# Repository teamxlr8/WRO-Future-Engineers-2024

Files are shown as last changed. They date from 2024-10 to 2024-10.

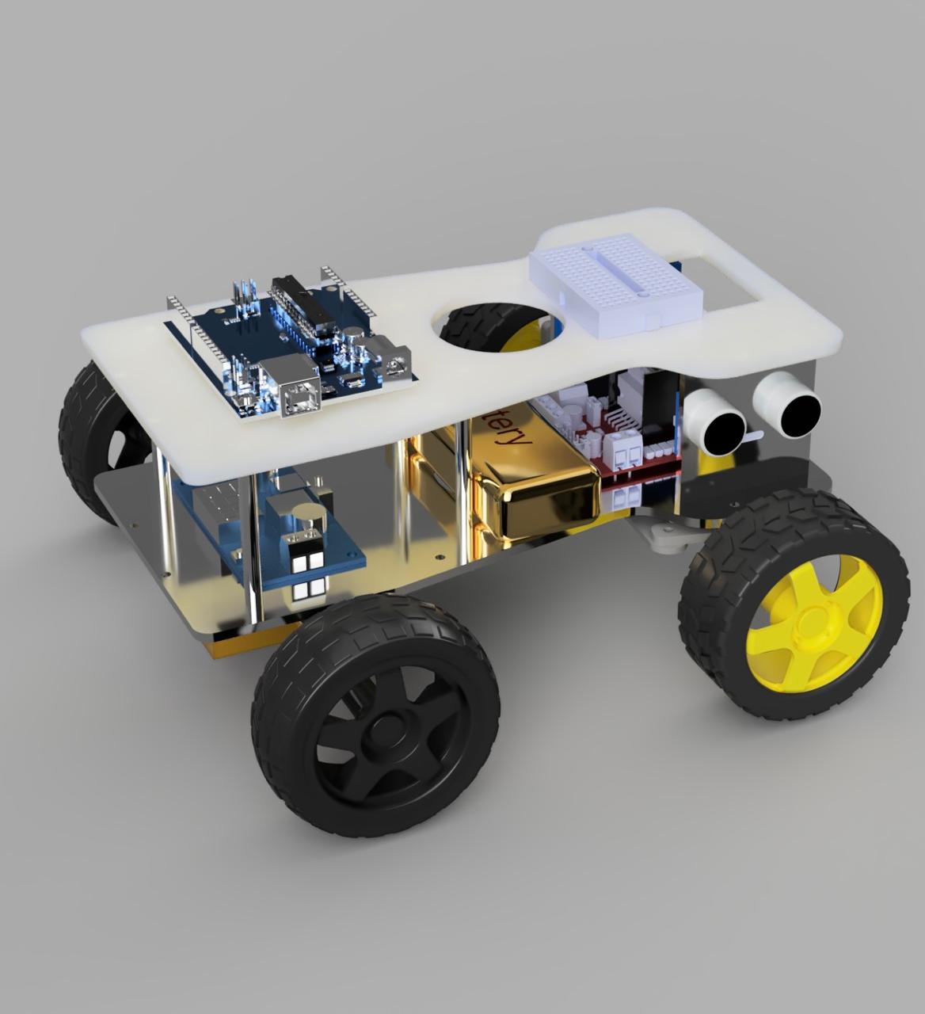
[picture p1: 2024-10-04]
models/6.jpeg

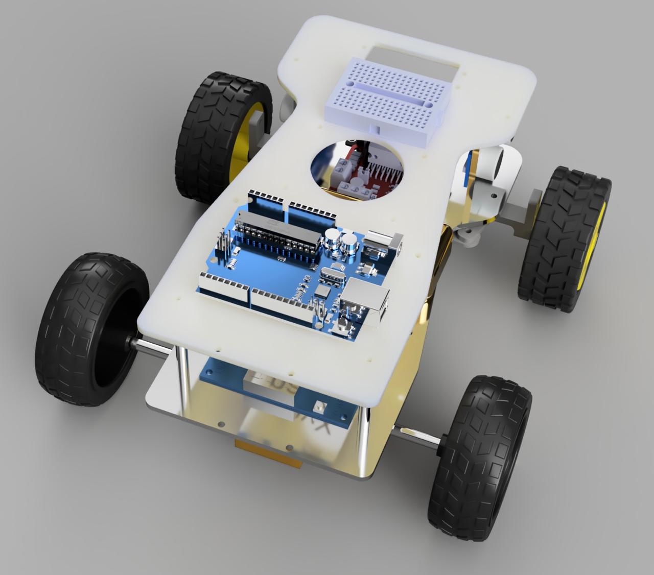
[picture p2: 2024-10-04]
models/4.jpeg

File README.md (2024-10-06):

# WRO Future Engineers 2024
## Introduction
Hello! This is team xlr8's WRO Future Engineer's repository. This repository includes details about our robot's construction, electricals, and software. We've recorded the progress of our robot and the various iterations we worked on throughout the process of preparing for the WRO competition.

As Team xlr8, our team's goal is to design and develop an advanced autonomous robot with precise steering capabilities to navigate a complex track effectively. Using engineering workflows and iterative testing, our intent is to optimize performance and showcase our innovation and problem-solving skills.

## Contents of This Repository
1. `t-photos`: Team Photos
2. `v-photos`: Robot's Photos
3. `video`: Video Demonstration of Our Running Robot
4. `schemes`: Schematic Diagrams
5. `src`: Software and Codes Required to Run Our Robot
6. `model`: Files for Model 
9. `other`: Detailed Descriptions of Components and Mechanisms

## Introduction
_This part must be filled by participants with the technical clarifications about the code: which modules the code consists of, how they are related to the electromechanical components of the vehicle, and what is the process to build/compile/upload the code to the vehicle’s controllers._

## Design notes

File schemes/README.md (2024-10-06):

This commit in our repository holds all the schematic diagrams that help understand the electricals connections in our robot.

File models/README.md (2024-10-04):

This folder holds the .step file for the final assembly of our robot, as well as photos of what it should look like. The .step file will help the viewer look into each part of the robot chassis and electricals, and it can make it easier to follow the tutorial using the timeline feature on Fusion 360. 

Since the .step file is too large to upload, we're adding a google drive link with the file uploaded on that: https://drive.google.com/drive/folders/1iC6DVvbiXgJcQIvjXP-3EXG4zTWpt-ap?usp=sharing

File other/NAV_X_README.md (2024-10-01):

We are using the NavX magnetometer in our robot in order to be able to measure and control the number of times the car circles around the inner boundary. Traditionally, the NavX magnetometer is a sensor commonly used in robotics and navigation applications to measure magnetic fields and determine orientation relative to the Earth's magnetic field. The core component of the NavX magnetometer is a 3-axis magnetometer, which measures the magnetic field strength along three perpendicular axes (X, Y, and Z). These measurements are often also refered to as roll, pitch and yaw respectively. We have explained these parameters in more detail below.

Moreover, the NavX sensor typically includes a microcontroller that processes the raw data from the magnetometer. The NavX magnetometer typically provides various interfaces for integration with robotics platforms, such as I2C, SPI, or UART. This makes it compatible with many microcontrollers and development boards. We have integrated the NavX with the Arduino Uno Board for this project.

Additionally, when combined with other sensors like accelerometers and gyroscopes, the NavX magnetometer can provide more accurate orientation and heading information through sensor fusion algorithms. These algorithms combine data from multiple sensors to reduce errors and noise. Also, to ensure accurate readings, the NavX magnetometer often requires calibration. This process involves moving the sensor through various orientations to map out and correct any magnetic distortions caused by nearby objects. For instance, the NavX magnetometer is used to help robots determine their heading and maintain a stable direction of travel. In automotive applications, the magnetometer can be used for electronic compasses and navigation systems. In our robot, we are using the NavX magnetometer to measure and account for turns taken. So, in each circle, the magnetometer should measure four turns, and should take three such circles with twelve total turns. We are integrating the NavX sensor with the Arduino board to be able to stop the robot when it does this.

Now, explaining the roll, pitch and yaw parameters… Yaw, pitch, and roll are three rotational degrees of freedom that describe the orientation of an object in 3D space. In the context of the NavX sensor, these terms refer to the angular orientation of a device, typically a robot or UAV, relative to its own coordinate system.

Roll is the rotation around the longitudinal axis (X-axis). It represents the tilt of the object from side to side. The NavX sensor measures roll using the accelerometer and gyroscope. The accelerometer detects the force of gravity to determine side-to-side tilt, while the gyroscope measures rotational changes around the longitudinal axis. Roll is essential for balance and stability. In a robot, the roll angle helps maintain equilibrium on uneven surfaces, while in a drone, it helps control the side-to-side tilt.

Pitch is the rotation around the lateral axis (Y-axis). It represents the tilt of the object forward or backward. The NavX sensor measures pitch using the accelerometer and gyroscope. The accelerometer detects the force of gravity, which indicates the tilt angle, while the gyroscope measures rotational changes around the lateral axis. Pitch is important for maintaining stability and orientation. For instance, in a drone, the pitch angle helps control the forward or backward tilt during flight.

Lastly, yaw is the rotation around the vertical axis (Z-axis). It represents the direction the object is facing horizontally, often referred to as the heading. In the NavX sensor, yaw is measured using the magnetometer and gyroscope. The magnetometer detects the direction of the Earth's magnetic field to determine heading, while the gyroscope measures rotational changes around the vertical axis. Yaw is crucial for navigation. For example, in a robot, the yaw angle helps determine the direction the robot is moving or facing.

The NavX sensor combines data from the accelerometer, gyroscope, and magnetometer to provide accurate measurements of yaw, pitch, and roll. This process, known as sensor fusion, involves filtering, calibration and fusion algorithms. Filtering is when raw data from each sensor is filtered to remove noise and improve accuracy. Then, sensors are calibrated to compensate for any biases or distortions. And lastly, advanced algorithms combine the data from all sensors to provide a stable and accurate estimate of the device's orientation.

While roll, pitch and yaw are all three equally important in understanding and manipulating the orientation of a robot, we will be focusing on the yaw value, since we just need to alter the robot’s ability to turn left or right, by adjusting its heading.

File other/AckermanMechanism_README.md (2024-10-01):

As mentioned in an earlier repository, we are using the Ackerman mechanism, which is linked to the servo motor, for the steering of the front two wheels. This mechanism, also known as Ackerman steering geometry, is a geometric arrangement of linkages in the steering of a vehicle. It is usually designed to solve the problem of wheels needing to trace out circles of different radii when steering. This mechanism is essential for ensuring that the wheels of a vehicle follow the correct path while turning, minimizing tire wear and improving handling. In our case, we are using this mechanism in order to improve the steering of our vehicle to the optimum level. This mechanism helped us because when we tried to directly connect the servo motor to the front two wheels, we saw that our robot was taking sharp turns and wasn’t able to control the same efficiently. However, this changed significantly when we tried the Ackerman steering. The mechanism provides more precise and predictable steering, enhancing vehicle control. Additionally, while testing, we also realised that by ensuring the wheels follow the correct path during a turn, the Ackerman mechanism reduces tire scrubbing and wear, hence improving the tire health.

How this mechanism traditionally works: When a vehicle turns, the inner and outer wheels must trace circles of different radii. The inner wheel needs to turn more sharply than the outer wheel. Ackerman steering geometry ensures that the inside front wheel turns at a sharper angle than the outside front wheel. It consists of three components, the steering arms (attached to the front wheels), the tie rods (connect the steering arms to the steering gear, which in our case is the servo motor) and the kingpin (the pivot point around which the wheel assembly turns, which in our case is an extension of the servo motor). Additionally, the correct Ackerman geometry involves positioning the steering arms such that, when extended, the lines drawn through the steering arms meet at the center of the rear axle. This ensures that all wheels are aligned with the turning circle's center. When the steering wheel is turned, the steering gear moves the tie rods, which in turn move the steering arms. Due to the specific angles and lengths of these components, the inner wheel turns more sharply than the outer wheel, maintaining the correct turning radii.

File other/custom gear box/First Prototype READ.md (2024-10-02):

This repository is for the custom gear box that we made for our robot. Initially, we were using the Rev Core Hex robot in our first prototype. The Rev Core Hex motor ran at a 125 rpm and weighed 200 grams. However, eventually we realised that this motor was functioning at a really slow speed. Even though this motor had a good torque but it was heavy, it had a very low rmp. Therefore, we weren't able to perform the task in an efficient manner with this motor. So, we tried to change the motor by using N20 motor which ran at 200 rpm and weighed 10 grams. This motor was light and had a high speed, but didn't have enough torque, so it wasn't a viable option either. Therefore, we finally decided to use the Bag motor which weighed 325 grams. For that, we needed to make a custom gear box, which has a 4:15 reduction (16:60). The pinion on the moitor runs at a 13,180 rpm which is powered by a Bag motor. This Bag motor is a VEX motor is a 13,180 rpm motor with 0.4 N-m stall torque. The 60 tooth gear connected to the output shaft by reduction gives a motor speed to 3,514 rpm. The reason that we have chosen to make the custom gear box is because we want to use a better motor. Here's the link to access the CAD for the custom gearbox https://grabcad.com/library/custom-gearbox-3 https://drive.google.com/file/d/15HoRaLY3t5rEGp8NuojFlwkP93zTSltt/view?usp=sharing

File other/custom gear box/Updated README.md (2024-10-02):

In our last iteration of the gear box, we were using readily available pinion gears and had attached those two together based on the CAD file we had created. However, when we actually made those changes on a box channel and then cut it and tested it, we realised that the two pinions were not compatible with each other. Due to this, there a slipping issue we weren't able to solve. The only way around this that we saw was creating our own custom pinion gear and then changing the gear box accordingly. So we did exactly that. Based on the new pinion, we altered the CAD file, after which we made a bigger and clearer drawing of the same on paper to clearly understand the intricate measurements. Based on these measurements, we created a new customised gear box in a C shape, and we are now going to test it.

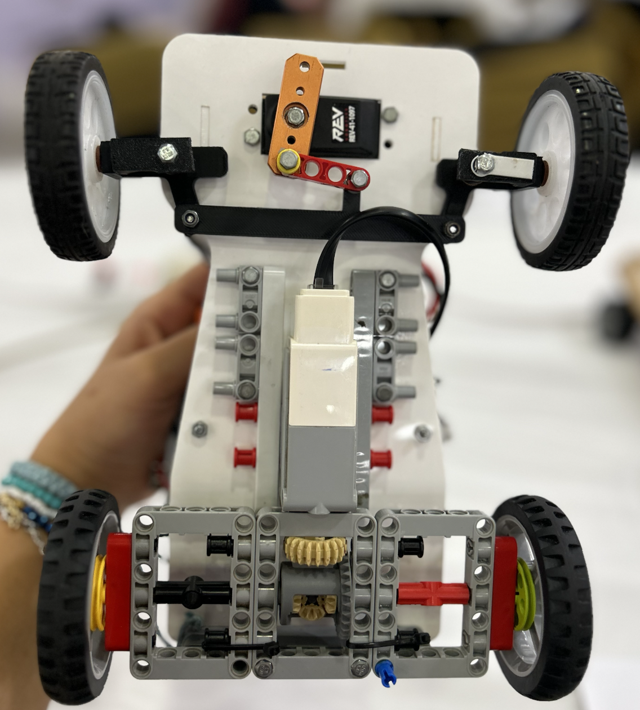
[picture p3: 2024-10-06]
v-photos/Bottom.png

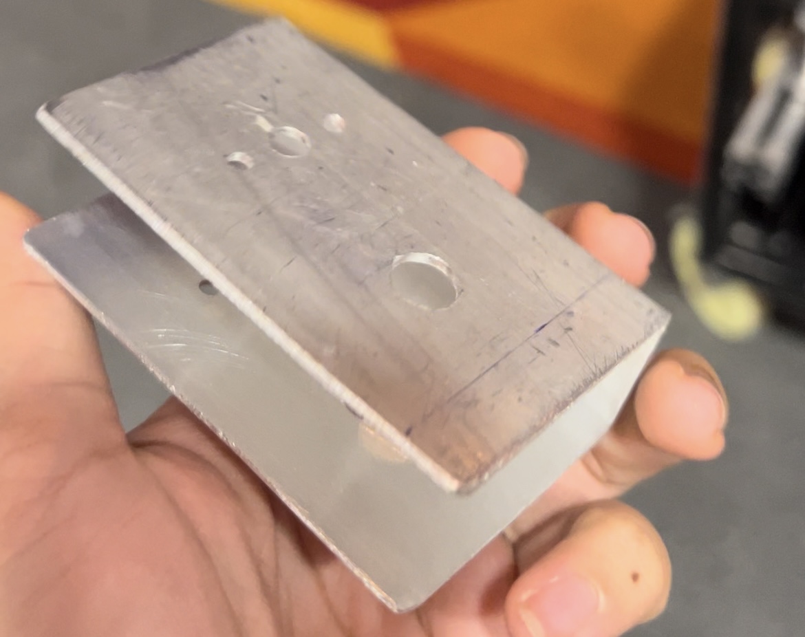
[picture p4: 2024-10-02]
other/custom gear box/Updated Gear Box 4.jpg

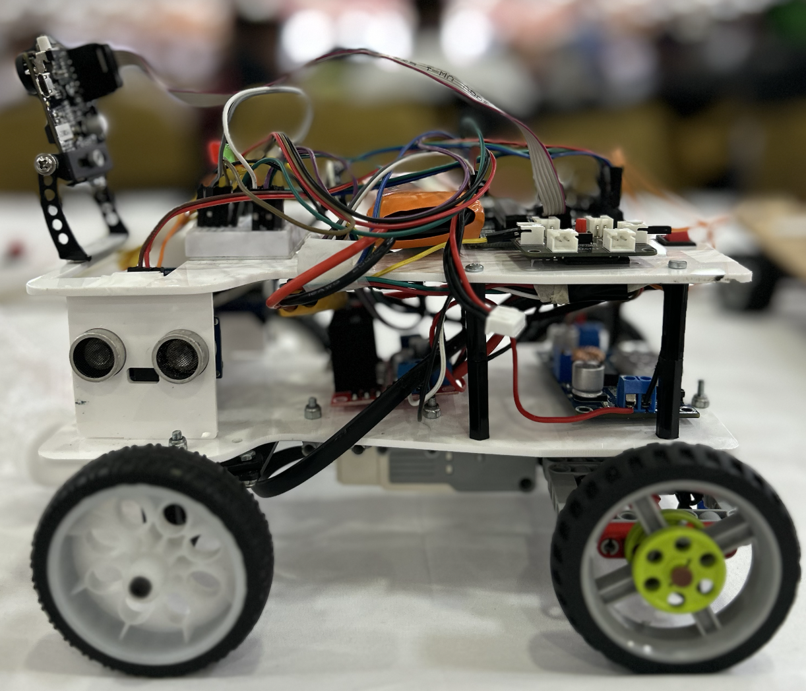
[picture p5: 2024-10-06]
v-photos/Right.png

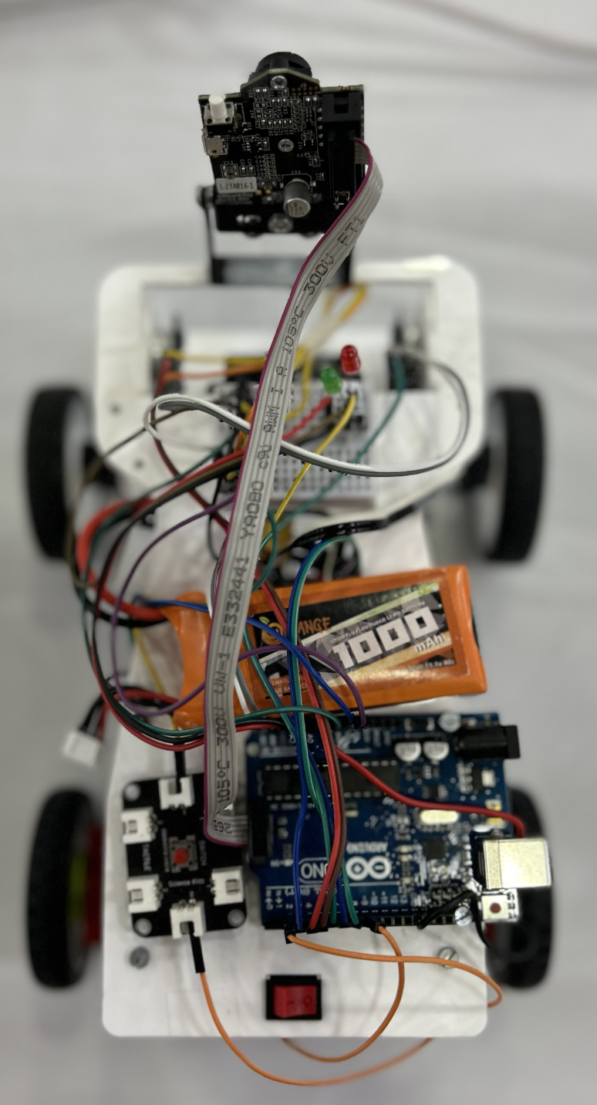
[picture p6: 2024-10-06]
v-photos/Top.png

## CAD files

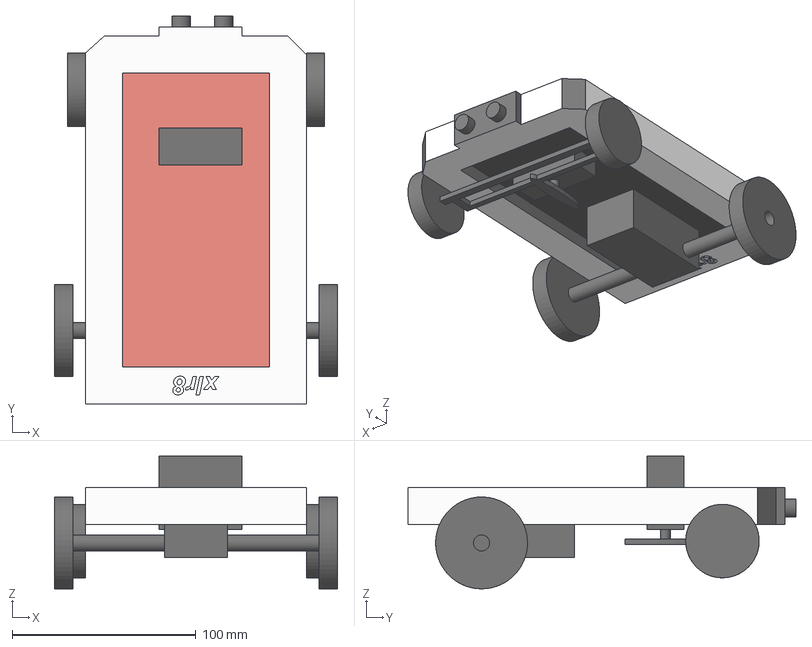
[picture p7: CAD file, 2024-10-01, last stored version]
models/Prototype1/Protoype1Teamxlr8 v1.step
154.0 x 211.0 x 72.2 mm

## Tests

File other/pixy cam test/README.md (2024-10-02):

This repository is for the initial test we ran on the Pixy Cam. First, we worked on downloading the Pixy Cam library on Arduino such that we could ensure that the two are compatible with each other. On doing so, we then proceeded to test the example code already available on Arduino. This was a simple test to ensure the connections were successful. After that, we started working on the most important part; which was to test whether or not the Pixy Cam was able to correctly detect colours, and transfer this information effectively to Arduino. To do so, we created a simple code in which we added a simple if-else logic. Using the same, we were able to make a LED/buzzer turn on for a long time when the first signature was detected-in other words, when red was detected for example- and we made the LED/buzzer blink when the second signature was detected, or when green was detected.

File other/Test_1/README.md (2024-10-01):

This repository is for the first test we ran on our robot. This code is for a simple wall follower robot, in which we have used utrasonic sensors to detect the distance between the outer and inner walls. According to the difference in the distance between the left and right ultrasonic sensors, the robot attempts to stay in the middle of the arena as much as possible.

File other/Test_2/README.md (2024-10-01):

This repository includes the second test we ran on our robot. In this code, we have added and made progress on the previous line following code. Here, we've used a NavX magnetometer, in which we have tried to limit the number of turns out line following robot takes based on the values detected and stored by the Nav X sensor. In a later repository we will add more information on the sensor we have used and how we are implementing the sensor's values.

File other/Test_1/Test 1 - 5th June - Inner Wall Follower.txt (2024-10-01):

#include <NewPing.h>
#include <Servo.h>

#define TRIGGER_PIN 14

#define ECHO_PIN 15

#define MAX_DISTANCE 500// Maximum distance we want to ping for (in centimeters). Maximum sensor distance is rated at 400-500cm.
NewPing sonar1(TRIGGER_PIN, ECHO_PIN, MAX_DISTANCE);
#define TRIGGER_PIN 12

#define ECHO_PIN 11

NewPing sonar2(TRIGGER_PIN, ECHO_PIN, MAX_DISTANCE);
Servo servo_pin_9;
int L = 0;
int F = 0;
String prefixstr = ""; 

void setup() {
  servo_pin_9.attach(9);
  Serial.begin(9600);
  pinMode(A3, INPUT);
  pinMode(2, OUTPUT);
  pinMode(3, OUTPUT);

  servo_pin_9.write( 90 );

}

void loop() {
  Serial.println(digitalRead(A3));
  L = sonar2.ping_cm();
  F = sonar1.ping_cm();
  Serial.print(prefixstr + "Left:"+sonar2.ping_cm() );
  Serial.println();
  Serial.print(prefixstr + "Front:"+sonar1.ping_cm() );
  Serial.println();
  digitalWrite( 2 , HIGH );
  digitalWrite( 3 , LOW );
  if (( ( L < 30 ) && ( L > 20 ) )) {
    servo_pin_9.write( 90 );
  }
  if (( L > 30 )) {
    servo_pin_9.write( 105 );
  }
  if (( ( L < 20 ) && ( L >= 0 ) )) {
    servo_pin_9.write( 75 );
  }
}

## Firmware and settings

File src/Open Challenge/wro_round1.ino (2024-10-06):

#include <NewPing.h>         // Ultrasonic sensor library
#include <Wire.h>
#include "AHRSProtocol.h"             // navX-Sensor Register Definition header file
#include <Servo.h>

#include <Pixy2.h>

// This is the main Pixy object 
Pixy2 pixy;


Servo myservo;  // create servo object to control a servo
// Constants for straight position and max steering angles
const int STRAIGHT = 90;  // Assuming 90 is straight
const int RIGHT_LIMIT = 120;
const int LEFT_LIMIT = 60;

#define motorA 8
#define motorB 3

#define green 17
#define yellow 16
#define start 2

// Ultrasonic sensor pins
#define TRIG_PIN_LEFT 4
#define ECHO_PIN_LEFT 5
#define TRIG_PIN_RIGHT 6
#define ECHO_PIN_RIGHT 7
#define TRIG_PIN_FRONT 14
#define ECHO_PIN_FRONT 15


// Initialize ultrasonic sensors
NewPing sonarLeft(TRIG_PIN_LEFT, ECHO_PIN_LEFT, 500);    // Left sensor
NewPing sonarRight(TRIG_PIN_RIGHT, ECHO_PIN_RIGHT, 500); // Right sensor
NewPing sonarFront(TRIG_PIN_FRONT, ECHO_PIN_FRONT, 500); // Front sensor
int leftDistance, rightDistance,frontDistance;

unsigned long previousUltrasonicMillis = 0;
unsigned long previousNavxMillis = 0;
unsigned long currentMillis = 0;
const unsigned long ultrasonicInterval = 50;  // Poll ultrasonic every 50 ms
const unsigned long navxInterval = 100;       // Poll NavX every 100 ms

//Initialize NavX parameters
byte data[512];
#define ITERATION_DELAY_MS                   10
#define NAVX_SENSOR_DEVICE_I2C_ADDRESS_7BIT  0x32
#define NUM_BYTES_TO_READ                    8
int register_address = NAVX_REG_YAW_L;

int direction = 0;

//PD variables
const int desiredDistance = 30;  // Ideal distance from the wall (in cm)                              //25
const float Kp = 1;            // Proportional control constant, tune this for smoothness           //1.0
const float Kd = 6; // Derivative gain                                                             //6
float previousError = 0;

// Variables for lap counting using NavX yaw
float currentYaw, previousYaw;
int lapCount = 0;
bool lapStartDetected = false;
bool turnCompleted = false; // New flag to detect full turns

// Yaw threshold for detecting 90-degree turns (adjust as necessary)
const int YAW_THRESHOLD = 40;
const int MAX_LAPS = 3;

bool passedLane1 = false;
bool passedLane2 = false;
bool passedLane3 = false;
bool passedLane4 = false;
bool reverse = false;  // Flag to track if the robot is moving in reverse

int initialYaw = 0;
float yawOffset = 0;  // This will hold the offset to set initial yaw to 90

bool passed90 = false;

// Variables for lap counting using NavX yaw
//float currentYaw, previousYaw;
//int lapCount = 0;
//bool lapStartDetected = false;



int x=0;
int y=0;

void setup() {
  Serial.begin(115200);

 pixy.init();
  //motor pins
  pinMode(motorA, OUTPUT);  
  pinMode(motorB, OUTPUT);

  pinMode(green,OUTPUT);
  pinMode(yellow,OUTPUT);
  pinMode(start,INPUT);
  digitalWrite(start,HIGH);
  //navX
   Wire.begin(); // join i2c bus (address optional for master)

  for ( int i = 0; i < sizeof(data); i++ ) {
      data[i] = 0;
  }
  
  myservo.attach(9);  //Servo pin
  steerStraight();

pixy.setLamp(1,1);
  delay(10000);
 Serial.println("Go XLR8.");
 digitalWrite(green,HIGH);
 initialYaw = getYaw();
 Serial.println(initialYaw);
 // Calculate the offset needed to make the initialYaw appear as 90 degrees
  yawOffset = 90 - initialYaw;
   Serial.print("Yaw Offset: ");
  Serial.println(yawOffset);
}

int mode = 0;
void loop() {

while(mode == 0)
  {
    Serial.println(digitalRead(start));
    if(digitalRead(start) == LOW)
    {
      mode = 1;break;  
    }
      
  }

while(mode == 1)
{
readultrasonics();
forward(130);
int DirCheck = leftDistance - rightDistance;
  if (DirCheck > -10 && DirCheck <10) {
    steerStraight();
    
  }
  else if (DirCheck <-10) {
    steerLeft(10);
  }

  else if (DirCheck >10) {
    steerRight(10);
  }


  
 // delay(1250);

 Serial.print("x");
 Serial.println(leftDistance);
 
 Serial.print("y");
 Serial.println(rightDistance);

if (rightDistance>=200) {
  Serial.println("GOing right");
  mode=2; break;
  
}

if (leftDistance>=200) {
  Serial.println("GOing left");
  mode=3; break;
}
}

while(mode == 2)  //rightwall
{
   currentMillis = millis();
  forward(150);
  
  // Poll Ultrasonic Sensors at regular intervals
  if (currentMillis - previousUltrasonicMillis >= ultrasonicInterval) {
    previousUltrasonicMillis = currentMillis;
    readultrasonics();  // Poll ultrasonic sensors
    innerwalllogicright();  // Update wall following logic
    rightlapcount();
   // pixyscan();
  }

  // Poll NavX Sensor at regular intervals
  if (currentMillis - previousNavxMillis >= navxInterval) {
    previousNavxMillis = currentMillis;
    // Stop the robot after completing 3 laps
    if (lapCount >= MAX_LAPS) {
      Serial.println("3 Laps Completed. Stopping Robot.");
      forward(150);
      delay(500);
      stop();
      delay(1000);
      while (1);  // Infinite loop to stop the robot
    }
  }
  
}



while(mode == 3)  //leftwall
{
  currentMillis = millis();
  forward(150);
  // Poll Ultrasonic Sensors at regular intervals
  if (currentMillis - previousUltrasonicMillis >= ultrasonicInterval) {
    previousUltrasonicMillis = currentMillis;
    readultrasonics();  // Poll ultrasonic sensors
    innerwalllogicleft();  // Update wall following logic
    leftlapcount();
   // pixyscan();
  }

  // Poll NavX Sensor at regular intervals
  if (currentMillis - previousNavxMillis >= navxInterval) {
    previousNavxMillis = currentMillis;
    // Stop the robot after completing 3 laps
    if (lapCount >= MAX_LAPS) {
      Serial.println("3 Laps Completed. Stopping Robot.");
      forward(150);
      delay(500);
      stop();
      delay(1000);
      while (1);  // Infinite loop to stop the robot
    }
  }
}
}
  



  




// Function to normalize yaw to the range -180 to 180 degrees
float normalizeYaw(float yaw) {
  if (yaw > 180) {
    yaw -= 360;
  } else if (yaw < -180) {
    yaw += 360;
  }
  return yaw;
}


void pixyscan()
{
int i; 
  // grab blocks!
  pixy.ccc.getBlocks();
  
  // If there are detect blocks, print them!
  if (pixy.ccc.numBlocks)
  {
    Serial.print("Detected ");
    Serial.println(pixy.ccc.numBlocks);
    for (i=0; i<pixy.ccc.numBlocks; i++)
    {
      Serial.print("  block ");
      Serial.print(i);
      Serial.print(": ");
      pixy.ccc.blocks[i].print();
    }

    if(pixy.ccc.blocks[0].m_signature == 2  && pixy.ccc.blocks[0].m_height > 40)
    {
      stop();
      digitalWrite(green,HIGH); 
      
    //  steerLeft(20);
      delay(10000);
      digitalWrite(green,LOW); 
     // steerStraight();
           
    }

    if(pixy.ccc.blocks[0].m_signature == 1  && pixy.ccc.blocks[0].m_height > 40)
    {
      
      digitalWrite(yellow,HIGH);      
      steerRight(20);
      delay(1000);
      digitalWrite(yellow,LOW); 
    //  steerStraight();
    }


    
  }    
  
}


void leftlapcount()
{

  // Get the current yaw reading and adjust it using the offset
  currentYaw = getYaw() + yawOffset;
  
  // Normalize the adjusted yaw to ensure it stays within the range -180 to 180
  currentYaw = normalizeYaw(currentYaw);

  Serial.println(currentYaw);
    // Check for passing through each lane's yaw range
  if (!passedLane1 && currentYaw >= 70 && currentYaw <= 110) {
    passedLane1 = true;
    Serial.println("Entered Lane 1 (Yaw: 80-100)");
  }

  if (passedLane1 && !passedLane4 && (currentYaw >= 160 && currentYaw <= 180) || (currentYaw >= -180 && currentYaw <= -160)) {
    passedLane4 = true;
    Serial.println("Entered Lane 4 (Yaw: 160 to 180)");
  }
  
 
  if (passedLane1 && passedLane4 && !passedLane3 && currentYaw >= -100 && currentYaw <= -70) {
    passedLane3 = true;
    Serial.println("Entered Lane 3 (Yaw: -100 to -70)");
  }
  
  if (passedLane1 && passedLane4 && passedLane3 && !passedLane2 && 
      ((currentYaw >= -20 && currentYaw <= 20) )) {
    passedLane2 = true;
    Serial.println("Entered Lane 2 (Yaw: -20 to 20)");
  }

  // If all lanes have been passed, count a lap and reset
  if ( passedLane2 && passedLane3 && passedLane4 && currentYaw >= 70 && currentYaw <= 100) {
    lapCount++;
    Serial.println("Lap Completed: " + String(lapCount));

    // Reset flags for next lap
    passedLane1 = false;
    passedLane2 = false;
    passedLane3 = false;
    passedLane4 = false;
  }  
  
  
}



void rightlapcount()
{
  // Get the current yaw reading and adjust it using the offset
  currentYaw = getYaw() + yawOffset;
  
  // Normalize the adjusted yaw to ensure it stays within the range -180 to 180
  currentYaw = normalizeYaw(currentYaw);

  Serial.println(currentYaw);
  // Check for passing through each lane's yaw range
  if (!passedLane1 && currentYaw >= 80 && currentYaw <= 100) {
    passedLane1 = true;
    Serial.println("Entered Lane 1 (Yaw: 80-100)");
  }
  if (passedLane1 && !passedLane2 && currentYaw >= -20 && currentYaw <= 20) {
    passedLane2 = true;
    Serial.println("Entered Lane 2 (Yaw: -20 to 20)");
  }
  if (passedLane1 && passedLane2 && !passedLane3 && currentYaw >= -100 && currentYaw <= -70) {
    passedLane3 = true;
    Serial.println("Entered Lane 3 (Yaw: -100 to -70)");
  }
  if (passedLane1 && passedLane2 && passedLane3 && !passedLane4 && 
      ((currentYaw >= 160 && currentYaw <= 180) || (currentYaw >= -180 && currentYaw <= -160))) {
    passedLane4 = true;
    Serial.println("Entered Lane 4 (Yaw: 160 to 180 or -160 to -180)");
  }

  // If all lanes have been passed, count a lap and reset
  if ( passedLane2 && passedLane3 && passedLane4 && currentYaw >= 80 && currentYaw <= 100) {
    lapCount++;
    Serial.println("Lap Completed: " + String(lapCount));

    // Reset flags for next lap
    passedLane1 = false;
    passedLane2 = false;
    passedLane3 = false;
    passedLane4 = false;
  }
  
  
}





void innerwalllogicleft()
{
  forward(150);
  // Calculate the error (difference from the ideal distance)
  int error =   leftDistance - desiredDistance;
 // int error =   leftDistance - rightDistance;
  // Apply proportional control to adjust the steering
  int steeringAdjustment = Kp * error + Kd * (error - previousError);;
  
  // Ensure steeringAdjustment is within the valid range for your steering mechanism
  steeringAdjustment = constrain(steeringAdjustment, -30, 30);  // Limiting the adjustment to -30 (left) to 30 (right)

  // Adjust steering based on error
  if (steeringAdjustment > 0) {
    steerRight(steeringAdjustment);   // Steer left if too close to the wall
  } else if (steeringAdjustment < 0) {
    steerLeft(abs(steeringAdjustment));  // Steer right if too far from the wall
  } else {
    steerStraight();  // Move straight if at the desired distance
  }

  previousError = error;
  // Short delay to stabilize readings
 // delay(40);
}


void innerwalllogicright()
{
  forward(150);
  // Calculate the error (difference from the ideal distance)
  int error =    desiredDistance - rightDistance;
  
  // Apply proportional control to adjust the steering
  int steeringAdjustment = Kp * error + Kd * (error - previousError);;
  
  // Ensure steeringAdjustment is within the valid range for your steering mechanism
  steeringAdjustment = constrain(steeringAdjustment, -30, 30);  // Limiting the adjustment to -30 (left) to 30 (right)

  // Adjust steering based on error
  if (steeringAdjustment > 0) {
    steerRight(steeringAdjustment);   // Steer left if too close to the wall
  } else if (steeringAdjustment < 0) {
    steerLeft(abs(steeringAdjustment));  // Steer right if too far from the wall
  } else {
    steerStraight();  // Move straight if at the desired distance
  }

  previousError = error;
  // Short delay to stabilize readings
 // delay(40);
}

void readultrasonics()
{
  // Measure distances from the walls
  leftDistance = sonarLeft.ping_cm();
  rightDistance = sonarRight.ping_cm();
  frontDistance = sonarFront.ping_cm();
  // Debug print the distances
//  Serial.print("Left: " + String(leftDistance) + " cm, ");
//  Serial.print("Right: " + String(rightDistance) + " cm");
//  Serial.print("Front: " + String(frontDistance) + " cm");
//  Serial.println();
//  
  
}


int getYaw()
{
 int i = 0;
  /* Transmit I2C data request */
  Wire.beginTransmission(NAVX_SENSOR_DEVICE_I2C_ADDRESS_7BIT); // Begin transmitting to navX-Sensor
  Wire.write(register_address);                                // Sends starting register address
  Wire.write(NUM_BYTES_TO_READ);                               // Send number of bytes to read
  Wire.endTransmission();                                      // Stop transmitting
  
  /* Receive the echoed value back */
  Wire.beginTransmission(NAVX_SENSOR_DEVICE_I2C_ADDRESS_7BIT); // Begin transmitting to navX-Sensor
  Wire.requestFrom(NAVX_SENSOR_DEVICE_I2C_ADDRESS_7BIT, NUM_BYTES_TO_READ);    // Send number of bytes to read
  delay(1);
  while(Wire.available()) {                                    // Read data (slave may send less than requested)
     data[i++] = Wire.read();
  }
  Wire.endTransmission();                                      // Stop transmitting

  /* Decode received data to floating-point orientation values */
  float yaw =     IMURegisters::decodeProtocolSignedHundredthsFloat((char *)&data[0]);   // The cast is needed on arduino
  /* Display orientation values */
//  Serial.print("yaw:  ");
//  Serial.print(yaw,2);
//
//  Serial.println("");

  delay(ITERATION_DELAY_MS);  

  return yaw;
  
}


void steerStraight() {
    myservo.write(STRAIGHT);   // Set servo to center/straight position
}

void steerRight(int angle) {
    int target = constrain(STRAIGHT + angle, STRAIGHT, RIGHT_LIMIT); // Constrain the angle to prevent exceeding limits
    myservo.write(target);    // Set servo to the calculated right angle
}

void steerLeft(int angle) {
    int target = constrain(STRAIGHT - angle, LEFT_LIMIT, STRAIGHT);  // Constrain the angle to prevent exceeding limits
    myservo.write(target);    // Set servo to the calculated left angle
}


void forward(int sp)
{
digitalWrite (motorA, LOW);
  analogWrite (motorB, sp);

}

void backward(int sp)
{
digitalWrite (motorB, HIGH);
  analogWrite (motorB, sp);

}

void stop()
{
  digitalWrite (motorA, LOW);
  analogWrite (motorB, 0);
}

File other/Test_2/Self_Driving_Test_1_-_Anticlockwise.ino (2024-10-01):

#include <Wire.h>
#include "AHRSProtocol.h"             // navX-Sensor Register Definition header file
#include <NewPing.h>
#include <Servo.h>

#define TRIGGER_PIN 14

#define ECHO_PIN 15

#define MAX_DISTANCE 500// Maximum distance we want to ping for (in centimeters). Maximum sensor distance is rated at 400-500cm.
NewPing sonar1(TRIGGER_PIN, ECHO_PIN, MAX_DISTANCE);
#define TRIGGER_PIN 12

#define ECHO_PIN 11
int z = 0;
NewPing sonar2(TRIGGER_PIN, ECHO_PIN, MAX_DISTANCE);
Servo servo_pin_9;
int L = 0;
int F = 0;
String prefixstr = "";

byte data[512];

#define ITERATION_DELAY_MS                   10
#define NAVX_SENSOR_DEVICE_I2C_ADDRESS_7BIT  0x32
#define NUM_BYTES_TO_READ                    8
float yaw;

int yawint ;
int lapcount = 0;
int oldyaw = 0;
int newyaw = 0;



void setup()
{
  servo_pin_9.attach(9);
  pinMode(A3, INPUT);
  pinMode(2, OUTPUT);
  pinMode(3, OUTPUT);


  servo_pin_9.write( 90 );
  Serial.begin(115200);
  Wire.begin(); // join i2c bus (address optional for master)

  for ( int i = 0; i < sizeof(data); i++ ) {
    data[i] = 0;
  }
  digitalWrite( 2 , LOW );
  digitalWrite( 3 , HIGH );
}
int x = 0;
int y = 0;

int register_address = NAVX_REG_YAW_L;

void loop()
{

  //Serial.println(digitalRead(A3));
  L = sonar2.ping_cm();
  F = sonar1.ping_cm();
  //Serial.print(prefixstr + "Left:"+sonar2.ping_cm() );
  //Serial.println();
  //Serial.print(prefixstr + "Front:"+sonar1.ping_cm() );
  //Serial.println();
  if (( ( L < 30 ) && ( L > 20 ) )) {
    servo_pin_9.write( 90 );
  }
  if (( L > 30 )) {
    servo_pin_9.write( 105 );
  }
  if (( ( L < 20 ) && ( L > 1 ) )) {
    servo_pin_9.write( 75 );
  }
  int i = 0;
  /* Transmit I2C data request */
  Wire.beginTransmission(NAVX_SENSOR_DEVICE_I2C_ADDRESS_7BIT); // Begin transmitting to navX-Sensor
  Wire.write(register_address);                                // Sends starting register address
  Wire.write(NUM_BYTES_TO_READ);                               // Send number of bytes to read
  Wire.endTransmission();                                      // Stop transmitting

  /* Receive the echoed value back */
  Wire.beginTransmission(NAVX_SENSOR_DEVICE_I2C_ADDRESS_7BIT); // Begin transmitting to navX-Sensor
  Wire.requestFrom(NAVX_SENSOR_DEVICE_I2C_ADDRESS_7BIT, NUM_BYTES_TO_READ);    // Send number of bytes to read
  delay(1);
  while (Wire.available()) {                                   // Read data (slave may send less than requested)
    data[i++] = Wire.read();
  }
  Wire.endTransmission();                                      // Stop transmitting

  /* Decode received data to floating-point orientation values */
  yaw =     IMURegisters::decodeProtocolSignedHundredthsFloat((char *)&data[0]);   // The cast is needed on arduino

  /* Display orientation values */
  Serial.print("yaw:  ");
  Serial.print(yaw, 2);
  Serial.print("yawint:");
  Serial.print(yawint);
  Serial.println("");

  delay(ITERATION_DELAY_MS);

  mapsides();
  /*x= yaw;

    z=x-z;
    Serial.println(y);
    if( x>=80)
    {
    y=y+1;}
    if ( y >= 12)
    {
        digitalWrite( 2 , LOW );
    digitalWrite( 3 , LOW );
    }*/

}


void mapsides()
{
  if (yaw > -20 && yaw < 20)
  {
    yawint = 0;
    newyaw = 0;
  }


  if (yaw > 60 && yaw < 99)
  {
    yawint = 1;
    newyaw = 1;
  }


  if (yaw > 150 && yaw < 185)
  {
    yawint = 2;
    newyaw = 2;
  }

  if (yaw > -180 && yaw < -155)
  {
    yawint = 3;
    newyaw = 3;
  }

  if (oldyaw == 1 and newyaw == 0)
  {
    lapcount++;
    Serial.println("LAP COMPLETED");
  }

  if (lapcount == 3)
  {
    Serial.println("STOPPING ROBOT");
    delay(1000);
    digitalWrite( 2 , LOW );
    digitalWrite( 3 , LOW );
    delay(20000);
  }


  oldyaw = yawint;

}
